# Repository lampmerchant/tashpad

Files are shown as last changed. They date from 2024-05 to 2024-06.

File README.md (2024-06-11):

# TashPad

An adapter to make a Super Famicom/NES controller appear to an ADB Macintosh as a Gravis GamePad, targeting the PIC12F1501 (8 pins, ~$0.96) microcontroller.

## Technical Details

The firmware translates the buttons by position, not by color.  The Select and Start buttons emulate the toggle switch on the Gravis GamePad, with Select moving it toward the directional pad and Start moving it toward the buttons.  The SFC controller's L and R buttons duplicate the functionality of the Y and X buttons, respectively.

The ADB protocol used by the Gravis Mac GamePad is documented [here](https://github.com/lampmerchant/tashnotes/blob/main/macintosh/adb/protocols/gravis_mac_gamepad.md).  The protocol used by the SFC controller is documented [here](https://gamesx.com/controldata/snesdat.htm).

### Building Firmware

Building the firmware requires Microchip MPASM, which is included with their development environment, MPLAB. Note that you must use MPLAB X version 5.35 or earlier or MPLAB 8 as later versions of MPLAB X have removed MPASM.

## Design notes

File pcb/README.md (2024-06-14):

# TashPad

This is a simple PCB design, using all through hole components (with the exeption of the SD connector). It's designed this way to be period correct and easy to build for people who don't like soldering SMT components. Most of the components are only there for RF and short protection (inspired from both old Macs and the SNES itself)

This folder contains the source KiKad files for the main board. Please check the Panels subfolder for the FR-4 front and back plates.

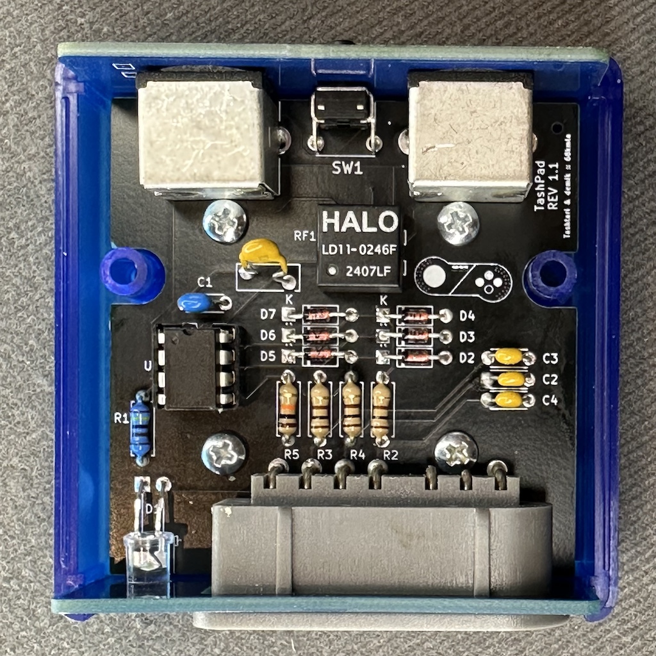
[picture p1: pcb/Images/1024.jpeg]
PCB


## BOM
### Mandatory
Here is the BOM for the main board. Part number are what was tested on prototypes board but you may find alternatives easily, especially resistors and sockets

| Reference(s) | Value | Quantity | Notes | Part number |
|---|---|---|---|---|
| C1 | 100nF | 1 | ceramic capacitor 5.08mm | Weltron 453358 |
| C2, C3, C4 | 330pF | 3 | ceramic capacitor 5.08mm | Vishay K331K15X7RF5TH5 |
| D1 | Green | 1 | 5mm any color 20 mA LED | Kingbright L-53SGD |
| D2 to D7 | 1N4148 | 6 | general purpose switching diode | Vishay 1N4148-TAP |
| F1 | 200mA Fuse | 1 | PPTC resettable fuse | Bourns MF-R020-2 |
| J1, J2 | Connector  | 2 | Mini DIN-4 (S-Video / ADB) | TE 5749181-1 |
| J3 | Connector  | 1 | SNES Angled (90°) connector | ??? right gray one |
| R2, R3, R4 | 100Ω | 3 | standard 0.25W carbon film resistor | TRU TC-CFR0W4J0101 |
| R1 | 330Ω | 1 | standard 0.25W carbon film resistor | TRU TC-CFR0W4J0331 |
| R5 | 10kΩ | 1 | standard 0.25W carbon film resistor | TRU TC-CFR0W4J0103 |
| SW1 | SPST | 1 | right angle SPST switch | TE FSMRA4JH04 |
| U1 | PIC | 1 | 8-bit Microcontrollers DIP PIC12F1501  | MC PIC12F1501-I/P |
| Case | ABS | 1 | Instrument Case, ABS 2.6x2.6" | HM 1593K(TBU\|GY\|BK)  |
| PCB Screws | #4 | 4 | Phillips Pan Head screws #4 x 1/4" | SERPAC 6004 |

### Optional

| Reference(s) | Value | Quantity | Notes | Part number |
|---|---|---|---|---|
| RF1 | 1:1:1:1 | 1 | common mode chokes / filters | HALO LD11-0246FLF |
| R1 | 2.4kΩ | 1 | standard 0.25W carbon film resistor | TRU CFR0W4J0222 |
| D1 | Blue | 1 | High efficiency 4000-8000mcd 5mm LED | Kingbright WP7113VRCBC |

:information_source: The common choke is recommended but pricey (about $5). When building without one, you need to bridge the pads as shown on the PCB

R1 + D1 combo replaces the 300Ω + 20mA LED combo by an high efficiency LED which will be run with only 1mA. This put less load on the ADB bus and is the recommended choice

Using sockets is also recommended because it will allow you to reclaim the microcontroler if your board is broken. This will also allow you to upgrade the firmware if a future firmware is released.

### BOM (external links)
Here is a complete mouser link (except the SNES connector).
- https://www.mouser.fr/ProjectManager/ProjectDetail.aspx?AccessID=4cef79201d

## PCBs
the PCBs are simple 2 layers boards. The gerbers are avaible in the release section.
Check for the following files:
* TashPad_1.1.zip: main board revision 1.1
* TashPad_back_panel_1.1.zip: FR-4 back panel revision 1.1
* TashPad_front_panel_1.0.zip: FR-4 back panel revision 1.0

You should be use any mainstream PCB manufacturer for theses. Nothing special about them. PCB thickness should be 1.6mm

On JLCPCB, select "Specify a location" to the option "Remove Order Number" for all of them

## Building
Building is straightworfard. It's recommended to start with small components first (diodes, then resistor, LED), then other components, and connectors last.

:warning: Please note thay you need to solder the SNES connector with the front panel in position at the same time! Otherwise you will not be able to mount the front panel

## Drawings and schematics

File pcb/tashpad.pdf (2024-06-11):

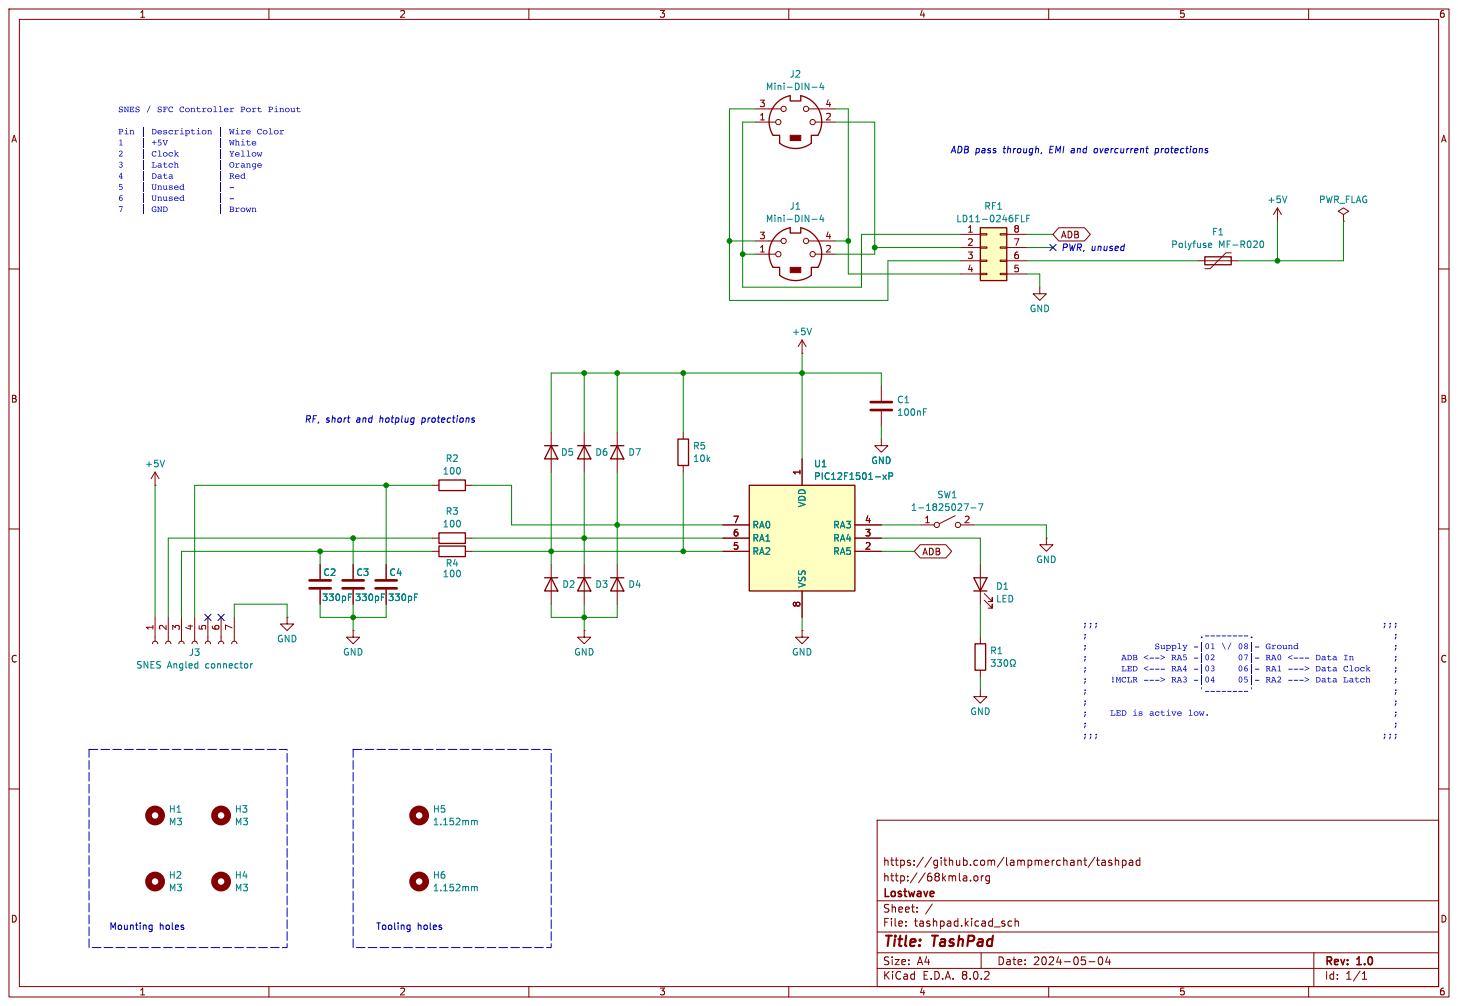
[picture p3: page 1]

http://68kmla.org
File: tashpad.kicad_sch Sheet: / Lostwave

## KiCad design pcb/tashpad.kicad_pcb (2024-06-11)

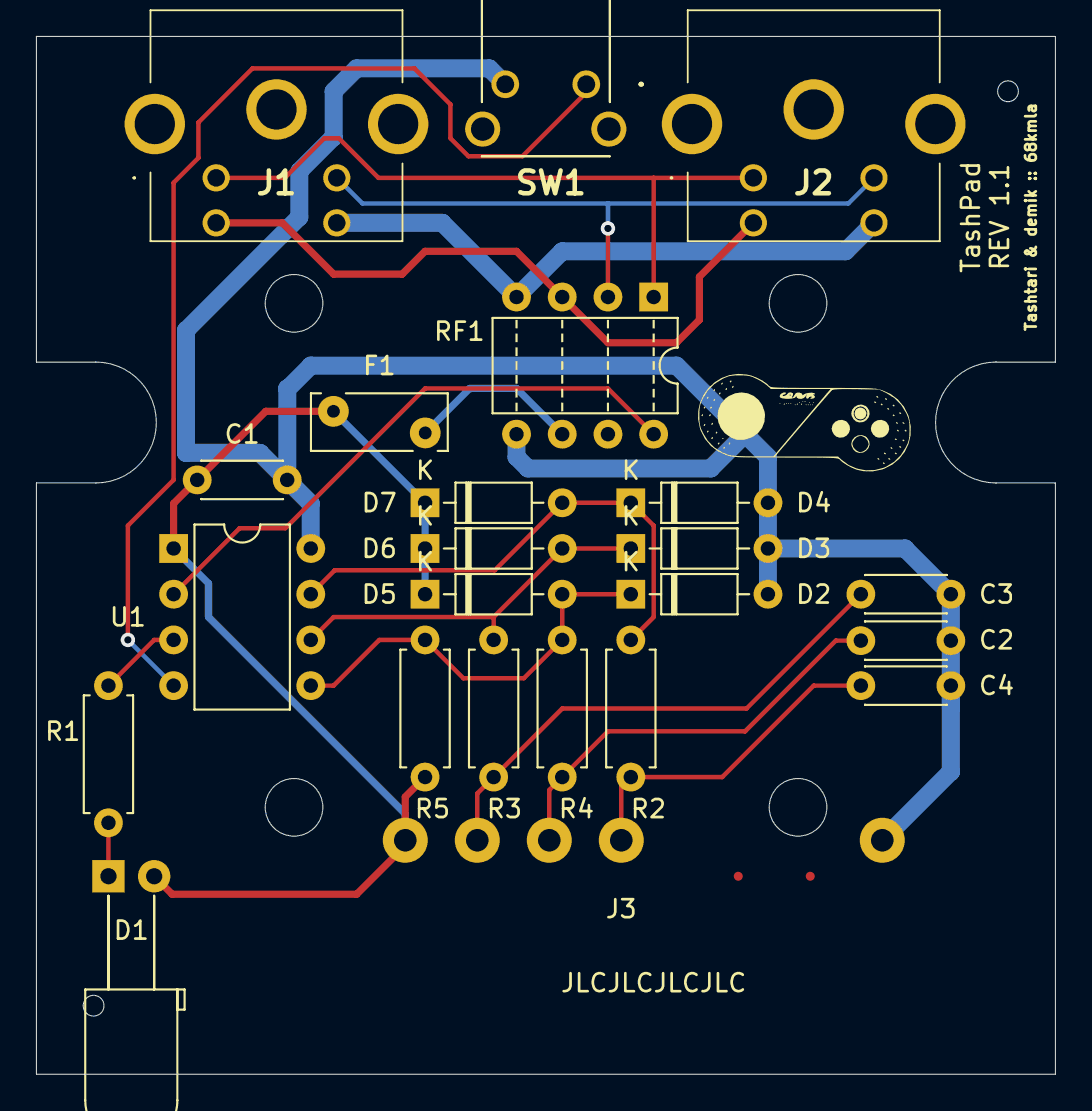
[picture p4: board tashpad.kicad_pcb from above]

Board: 2 copper layers, 56.6 x 57.7 mm, 29 parts (0 on the bottom side), 16 nets.

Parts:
C1: 100nF; C_Disc_D4.3mm_W1.9mm_P5.00mm
C2, C3, C4: 330pF; C_Disc_D4.3mm_W1.9mm_P5.00mm
D1: LED; LED_D5.0mm_Horizontal_O6.35mm_Z3.0mm
D2, D3, D4, D5, D6, D7: 1N4148; D_DO-35_SOD27_P7.62mm_Horizontal
F1: Polyfuse MF-R020; Fuse_Bourns_MF-RHT050
H1, H2, H3, H4: M3; MountingHole_3.2mm_M3
H5, H6: 1.152mm; MountingHole_1.152mm
J1, J2: Mini-DIN-4; 57491811
J3: SNES Angled connector; SNES Controller
R1: 330Ω; R_Axial_DIN0207_L6.3mm_D2.5mm_P7.62mm_Horizontal
R2, R3, R4: 100; R_Axial_DIN0207_L6.3mm_D2.5mm_P7.62mm_Horizontal
R5: 10k; R_Axial_DIN0207_L6.3mm_D2.5mm_P7.62mm_Horizontal
RF1: LD11-0246FLF; DIP-8_W7.62mm
SW1: 1-1825027-7; 118250277
U1: PIC12F1501-xP; DIP-8_W7.62mm

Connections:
+5V: C1.2, D1.2 (A), D5.1 (K), D6.1 (K), D7.1 (K), F1.2, J3.1, R5.1, U1.1 (VDD)
ADB: RF1.8, U1.2 (RA5)
GND: C1.1, C2.2, C3.2, C4.2, D2.2 (A), D3.2 (A), D4.2 (A), J3.7, RF1.5, SW1.2 (B), U1.8 (VSS)
unnamed: D1.1 (K), R1.1
unnamed: D2.1 (K), D5.2 (A), R4.2, R5.2, U1.5 (RA2)
unnamed: D3.1 (K), D6.2 (A), R3.2, U1.6 (RA1)
unnamed: D4.1 (K), D7.2 (A), R2.2, U1.7 (RA0)
unnamed: C3.1, J3.2, R3.1
unnamed: C2.1, J3.3, R4.1
unnamed: C4.1, J3.4, R2.1
unnamed: J1.1, J2.1, RF1.1
unnamed: J1.2, J2.2, RF1.2
unnamed: J1.3, J2.3, RF1.3
unnamed: J1.4, J2.4, RF1.4
unnamed: SW1.1 (A), U1.4 (RA3)
unnamed: R1.2, U1.3 (RA4)

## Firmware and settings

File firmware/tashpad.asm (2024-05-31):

;;; 80 characters wide please ;;;;;;;;;;;;;;;;;;;;;;;;;; 8-space tabs please ;;;


;
;;;
;;;;;  TashPad: Emulator for Gravis GamePad using Super Famicom Controller
;;;
;


;;; Connections ;;;

;;;                                                   ;;;
;                    .--------.                         ;
;            Supply -|01 \/ 08|- Ground                 ;
;      ADB <--> RA5 -|02    07|- RA0 <--- Data In       ;
;      LED <--- RA4 -|03    06|- RA1 ---> Data Clock    ;
;    !MCLR ---> RA3 -|04    05|- RA2 ---> Data Latch    ;
;                    '--------'                         ;
;                                                       ;
;    LED is active low.                                 ;
;                                                       ;
;;;                                                   ;;;


;;; Assembler Directives ;;;

	list		P=PIC12F1501, F=INHX32, ST=OFF, MM=OFF, R=DEC, X=ON
	#include	P12F1501.inc
	errorlevel	-302	;Suppress "register not in bank 0" messages
	errorlevel	-224	;Suppress TRIS instruction not recommended msgs
	__config	_CONFIG1, _FOSC_INTOSC & _WDTE_OFF & _PWRTE_ON & _MCLRE_ON & _CP_OFF & _BOREN_OFF & _CLKOUTEN_OFF
			;_FOSC_INTOSC	Internal oscillator, I/O on RA5
			;_WDTE_OFF	Watchdog timer disabled
			;_PWRTE_ON	Keep in reset for 64 ms on start
			;_MCLRE_ON	RA3/!MCLR is !MCLR
			;_CP_OFF	Code protection off
			;_BOREN_OFF	Brownout reset off
			;_CLKOUTEN_OFF	CLKOUT disabled, I/O on RA4
	__config	_CONFIG2, _WRT_OFF & _STVREN_ON & _BORV_LO & _LPBOR_OFF &_LVP_OFF
			;_WRT_OFF	Write protection off
			;_STVREN_ON	Stack over/underflow causes reset
			;_BORV_LO	Brownout reset voltage low trip point
			;_LPBOR_OFF	Low power brownout reset disabled
			;_LVP_OFF	High-voltage on Vpp to program


;;; Macros ;;;

DELAY	macro	value		;Delay 3*W cycles, set W to 0
	movlw	value
	decfsz	WREG,F
	bra	$-1
	endm

DNOP	macro
	bra	$+1
	endm


;;; Constants ;;;

KBDHDLR	equ	0x02	;ADB handler ID when in keyboard mode (default)
PADHDLR	equ	0x34	;ADB handler ID when in gamepad mode

;Pin Assignments:
DAT_PIN	equ	RA0	;Data input pin
CLK_PIN	equ	RA1	;Data clock pin
LAT_PIN	equ	RA2	;Data latch pin
LED_PIN	equ	RA4	;LED pin
ADB_PIN	equ	RA5	;ADB pin

;FLAGS:
PADMODE	equ	7	;Set when device is in gamepad mode
SWRIGHT	equ	6	;Set when gamepad switch is set to the right
SRQENBL	equ	5	;Set when SRQs are enabled
COLLIDE	equ	4	;Set when the last transmission collided
TXEVENT	equ	3	;Set when the state machine wants Tx events

;AP_FLAG:
AP_RST	equ	7	;Set when a reset condition is detected, user clears
AP_COL	equ	6	;Set when the transmission collided, user clears
AP_RXCI	equ	5	;Set when command byte in AP_BUF, user clears
AP_RXDI	equ	4	;Set when data byte in AP_BUF, user clears
AP_DONE	equ	3	;Set when transmission or reception done, user clears
AP_TXI	equ	2	;User sets after filling AP_BUF, interrupt clears
AP_SRQ	equ	1	;User sets to request service, user clears
AP_RISE	equ	0	;Set when FSA should be entered on a rising edge too


;;; Variable Storage ;;;

	cblock	0x70	;Bank-common registers
	
	FLAGS	;You've got to have flags
	AP_FLAG	;ADB flags
	AP_FSAP	;Pointer to where to resume ADB FSA
	AP_SR	;ADB shift register
	AP_BUF	;ADB buffer
	AP_DTMR	;ADB down-cycle timer value
	AC_FSAP	;Pointer to where to resume ADB user program state
	AC_ADDR	;ADB address of gamepad
	AC_TEMP	;Temporary variable between FSA states
	SF_FSAP	;Pointer to where to resume Super Famicom controller FSA
	SF_PADS	;Super Famicom converted to gamepad button state
	SF_LAST	;Last gamepad button state
	X3
	X2
	X1
	X0
	
	endc

	;FSR0 - Button state queue pop pointer
	;FSR1 - Button state queue push pointer

	;Linear memory:
	;0x2000-0x201F - Button state queue
	;0x2020-0x202F - unused


;;; Vectors ;;;

	org	0x0		;Reset vector
	goto	Init

	org	0x4		;Interrupt vector
	;fall through


;;; Interrupt Handler ;;;

Interrupt
	bcf	STATUS,C	;Copy the Timer0 flag into the carry bit so it
	btfsc	INTCON,TMR0IF	; doesn't change on us mid-stream
	bsf	STATUS,C	; "
	btfsc	STATUS,C	;If the Timer0 flag is set and the interrupt is
	btfss	INTCON,TMR0IE	; enabled, handle it as an event for the ADB
	bra	$+2		; state machine
	call	IntAdbTimer	; "
	movlb	7		;If the ADB pin has had a negative or positive
	btfsc	IOCAF,ADB_PIN	; edge, handle it as an event for the ADB state
	call	IntAdbEdge	; machine
	retfie

IntAdbTimer
	movlb	1		;Disable the Timer0 interrupt
	bcf	INTCON,TMR0IE	; "
	movf	AP_FSAP,W	;Resume the ADB state machine
	movlp	high AdbFsa	; "
	callw			; "
	movwf	AP_FSAP		;On return, save the address returned in W
	bcf	INTCON,TMR0IF	;Clear the Timer0 interrupt flag and its mirror
	bcf	STATUS,C	; in the carry bit
	return
	
IntAdbEdge
	movlw	1 << ADB_PIN	;Toggle the edge that the IOC interrupt catches
	xorwf	IOCAN,F		; "
	xorwf	IOCAP,F		; "
	bcf	IOCAF,ADB_PIN	;Clear the interrupt flag
	btfsc	IOCAN,ADB_PIN	;If the edge we just caught is a rising edge,
	bra	IntAdbRising	; jump ahead, otherwise fall through
	;fall through

IntAdbFalling
	movlb	0		;If Timer0 overflowed, this falling edge is
	btfsc	STATUS,C	; the first after a too-long period, so handle
	bra	IntAdbTimeout	; it as a timeout
	movf	AP_FSAP,W	;Resume the ADB state machine
	movlp	high AdbFsa	; "
	callw			; "
	movwf	AP_FSAP		;On return, save the address returned in W
	bcf	INTCON,TMR0IF	;Clear the Timer0 interrupt flag
	return

IntAdbRising
	movlb	0		;If Timer0 overflowed, this rising edge is at
	btfsc	STATUS,C	; the end of a reset pulse
	bra	IntAdbReset	; "
	movf	TMR0,W		;Save the current value of Timer0 so it can be
	movwf	AP_DTMR		; considered after its corresponding falling
	clrf	TMR0		; edge, then clear it and its flag
	bcf	INTCON,TMR0IF	; "
	btfss	AP_FLAG,AP_RISE	;If the flag isn't set that the state machine
	return			; wants to be resumed on a rising edge, done
	movf	AP_FSAP,W	;Resume the ADB state machine
	movlp	high AdbFsa	; "
	callw			; "
	movwf	AP_FSAP		;On return, save the address returned in W
	bcf	INTCON,TMR0IF	;Clear the Timer0 interrupt flag
	return

IntAdbReset
	bsf	AP_FLAG,AP_RST	;Set the reset flag
	clrf	AP_DTMR		;Clear the down timer
	;fall through

IntAdbTimeout
	clrf	AP_FSAP		;Reset the ADB state machine
	clrf	TMR0		;Reset Timer0 and its flag and disable its
	bcf	INTCON,TMR0IF	; interrupt
	bcf	INTCON,TMR0IE	; "
	return


;;; Hardware Initialization ;;;
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

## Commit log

2024-06-10 initial PCB release (main board + FR-4 panels)
    [tashpad.kicad_pcb, tashpad.kicad_sch, tashpad_BP.kicad_pcb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]
2024-06-11 added ReadMe for BOM + Photo
2024-06-12 PCB ReadMe updates
2024-06-14 Updated BOM + Mouser link
